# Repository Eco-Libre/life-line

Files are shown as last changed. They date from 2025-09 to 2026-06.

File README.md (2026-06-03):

# Eco-Libre Life-Line

This repo contains designs for an off-grid community's water system.

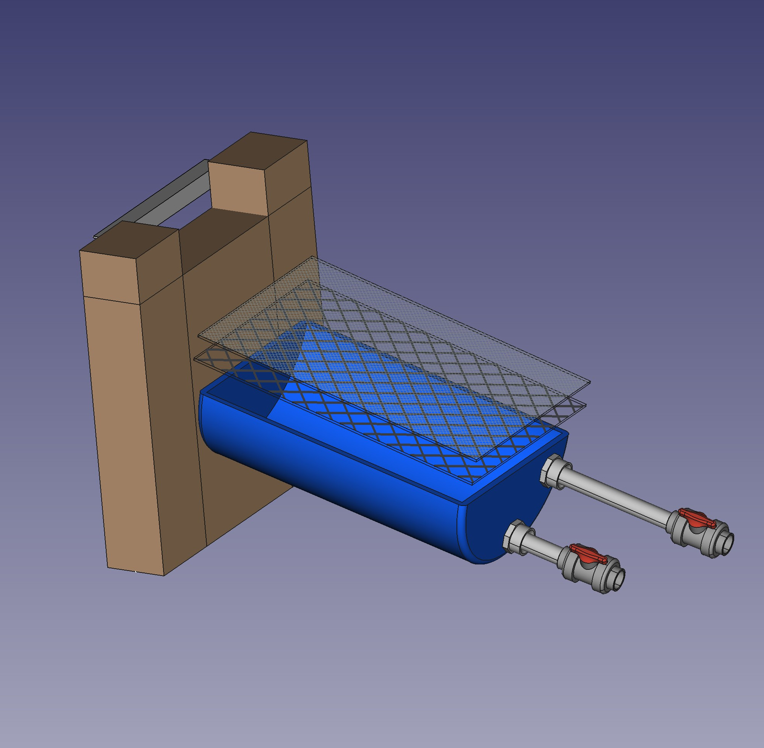
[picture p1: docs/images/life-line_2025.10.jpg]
Screenshot of CAD file
</a>

# Documentation

For more information (and build instructions), please see the [Eco-Libre Life-Line Documentation](https://eco-libre.github.io/life-line/)

 * https://eco-libre.github.io/life-line/

# License(s)

Copyright (C) 2023 Michael Altfield and Eco-Libre

The contents of this repo are licensed differently, depending on the 
file. In general:

 1. Most software files are licensed under AGPL-3.0-only

 3. Most other files are licensed CC-BY-SA-4.0

 4. Exceptions are defined according to the debian/copyright specification

To determine which license applies to which file, please see the 
`copyright` file. For more information on how to read and process 
this file, please see the specification here:

 * https://www.debian.org/doc/packaging-manuals/copyright-format/1.0/

The contents of this repo are distributed in the hope that it will be 
useful, but WITHOUT ANY WARRANTY; without even the implied warranty 
of MERCHANTABILITY or FITNESS FOR A PARTICULAR PURPOSE.  See the 
licenses under the LICENSES/ directory for more information.

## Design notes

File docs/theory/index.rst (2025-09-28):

.. _theory:

Theory
======

This section will describe the research behind this project and how it would benefit the lives of your community.

Concept
-------

The Eco-Libre Life-Line project is a system designed to collect, filter, and store surface water for an off-grid community.

Design Goals
------------

The water system should be:

#. Low-Maintenance
#. Hygienic

Low-Maintenance
---------------

**Low-Maintenance** means that low-tech automation and well-engineered, self-cleaning systems should be employed so that the system only needs routine maintenance once or twice per year.

Hygienic
--------

**Hygienic** means that the water stored in the clean water tanks and delivered to sinks should free of contamination (bacteria, parasites) and be safe to drink.

Size
----

**Pico (3-person)** (the smallest Eco-Libre Life-Line water system) should provide sufficient water for 3-people.

**Nano (15-person)** The small-size system should be horizontally scalable by multiplying the number of filters and tanks to provide sufficient water for a 15-person community

**Micro (30-person)** To handle a community of up to 30-people, a larger system design is provided.

**Milli (150-person)** To handle a community of up to 150-people, the micro system is horizontally scaled.

.. _theory_components:

Components
----------

Intake
^^^^^^

The water intake will consist of a weir on a stream with two openings with turbulence bars that channel turbulent water down onto a screen-covered 220-liter barrel angled at at downward slope.



  CAD Design of the Eco-Libre Life-Line's "Intake" component

This is a common low-budget, self-cleaning intake design that will shed organic debris during high-flow (eg a heavy rain).

The distance from the bottom of the weir to the top of the screen should be at least 20 cm.

The size of the holes in the screen should be 1-5 mm (it should be supported by a expanded metal screen below it).

The screen on the barrel should be mounted on a hinge to allow for routine maintenance.

Settling Tank
^^^^^^^^^^^^^

A radial-flow settling tank should be located very near to the intake and will remove sediment that passed the intake screen.

Large Sediment Filter
^^^^^^^^^^^^^^^^^^^^^

A self-cleaning spin down filter (largest size micron available) will remove debris that passed through the settling tank.

The flush valve should be automatically opened electronically by a timer.

Pre-Filter
^^^^^^^^^^

This pre-filter will remove turbidity from the water before it enters the slow sand filter.

This is `built <https://web.archive.org/web/20070728135100/http://www.refugeecamp.org/learnmore/water/slow_sand_filter.htm>`_ from a 220-litre HDPE drum that's filled with rocks and (mostly coarse) sand.

Slow Sand Filter
^^^^^^^^^^^^^^^^

The `Slow Sand Filter <https://en.wikipedia.org/wiki/Slow_sand_filter>`_ will remove harmful bacteria and parasites from the water.

This is `built <https://web.archive.org/web/20070728135100/http://www.refugeecamp.org/learnmore/water/slow_sand_filter.htm>`_ from a 220-litre HDPE drum that's filled with rocks and (mostly fine) sand.

Media Sediment Filter
^^^^^^^^^^^^^^^^^^^^^

A self-cleaning spin down filter (smallest size micron available) will remove filtering media debris (sand) that may have come-out of the filters

The flush valve should be automatically opened electronically by a timer.

Clean Water Tank
^^^^^^^^^^^^^^^^

The clean water tank stores potable water.

Lifeline
^^^^^^^^

Pipes supply clean water from the clean water tanks to the community.

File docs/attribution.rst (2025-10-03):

.. _attribution:

Attribution
===========

Thank you to the following folks who have contributed to the Life-Line project!
 * `Michael Altfield <maltfield_>`_
 * `Jack Nugent <jnugent_>`_
 * `Boris Plotkin <bplotkin_>`_
 * `Vegan Beasts <vbeasts_>`_

This project would not have been possible without the following tools and services:
 * `Python <https://www.python.org/>`_
 * `FreeCAD <https://www.freecad.org/>`_
 * `Vim <https://www.vim.org/>`_ 
 * `Gimp <https://www.gimp.org/>`_
 * `Kdenlive <https://kdenlive.org/en/>`_
 * `Sphinx <https://www.sphinx-doc.org/en/master/>`_
 * `Read The Docs <https://readthedocs.org/>`_
 * `Roboto Font <https://fonts.google.com/specimen/Roboto#about>`_
 * `Material Design Icons <https://github.com/google/material-design-icons>`_
 * `Wordpress <https://wordpress.com/>`_
 * `phpList <https://www.phplist.org/>`_
 * `QubesOS <https://www.qubes-os.org/>`_
 * `Debian <https://www.debian.org/>`_ `GNU <http://www.gnu.org/>`_/`Linux <https://www.kernel.org/>`_

Similar Projects
----------------

The reader may be interested to investigate the following similar projects:

 * `Gaviotas <https://en.wikipedia.org/wiki/Gaviotas>`_

.. _maltfield: https://www.michaelaltfield.net
.. _bplotkin: https://t.me/borisplot
.. _jnugent: https://github.com/Matterhorn777
.. _vbeasts: https://www.instagram.com/veganbeasts

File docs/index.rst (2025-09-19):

.. |nbsp| unicode:: 0xA0
   :trim:

Welcome to Eco-Libre's Life-Line documentation!
===================================================

Welcome! This is the official documentation for the Eco-Libre Life-Line.



  CAD Design of the Eco-Libre Life-Line

.. note::
   Just want to know **how to build the Eco-Libre Life-Line**?

   See our :ref:`Build Instructions <build>`

.. toctree::
   :maxdepth: 2
   :caption: What is the Life-Line?:
   :titlesonly:

   introduction/index
   theory/index
   praxis/index
   faq

.. toctree::
   :maxdepth: 3
   :caption: Build Instructions:
   
   build/index
   build/intake/index
   build/settling-tank/index
   build/large-sediment_filter/index
   build/pre_filter/index
   build/slow_sand_filter/index
   build/clean_water_tank/index
   build/lifeline/index

.. toctree::
   :maxdepth: 2
   :caption: Contributing:

   dev/index

.. toctree::
   :maxdepth: 2
   :caption: More:

   support
   changelog
   license
   attribution

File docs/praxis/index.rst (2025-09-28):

.. _praxis:

Praxis
======

This section will show example builds of the Eco-Libre Life-Line around the world.

Boris Plotkin
*************

In Nov 2024, `Boris Plotkin <bplotkin_>`_ built the first prototype of the Life-Line at the `Fruit Haven <fruithaven_>`_ community in Morona-Santiago, Ecuador

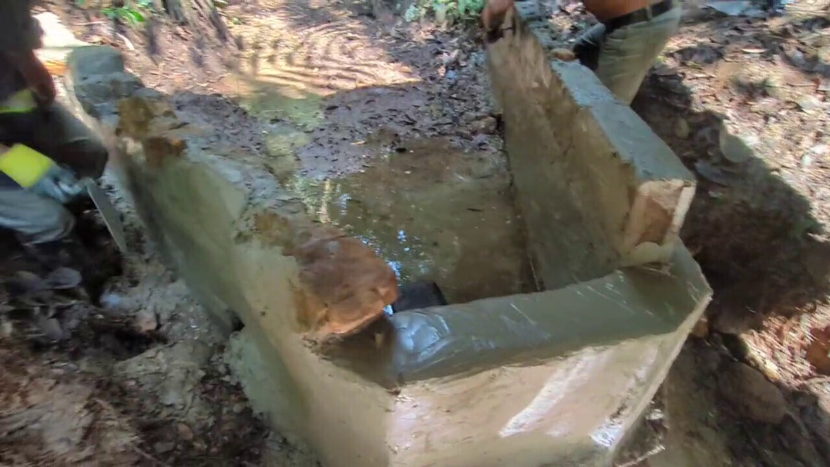
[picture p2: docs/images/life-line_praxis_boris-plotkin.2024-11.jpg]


  Concrete Block, Rock, and Cement Weir for the Eco-Libre Life-Line at Fruit Haven in Morona-Santiago, Ecuador (attribution: `Boris Plotkin <bplotkin_>`_)

Vegan Beasts
*************

In Apr 2025, `Vegan Beasts <vbeasts>`_ built the second prototype of the Life-Line at the `Fruit Haven <fruithaven_>`_ community in Morona-Santiago, Ecuador

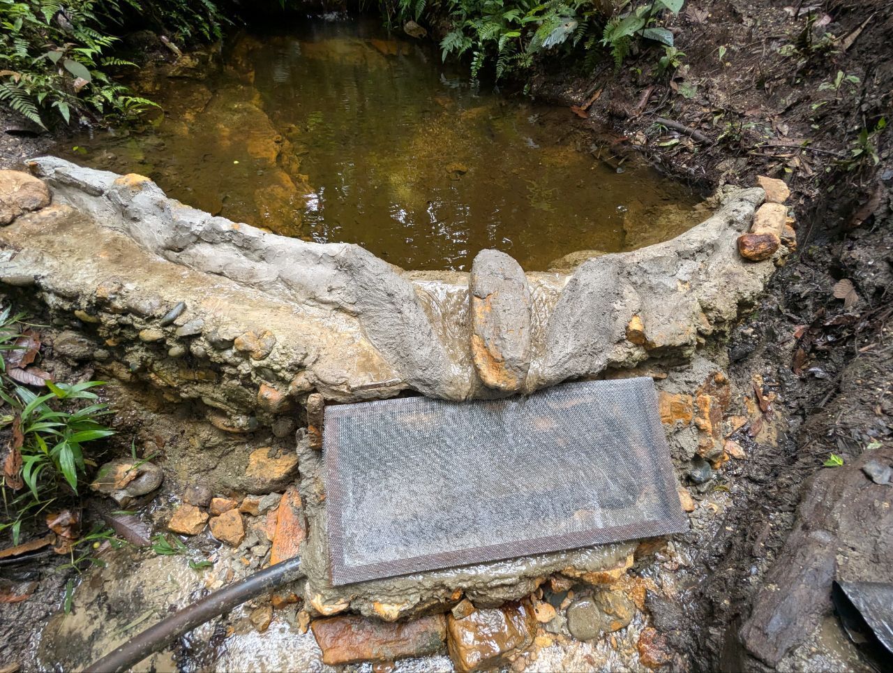
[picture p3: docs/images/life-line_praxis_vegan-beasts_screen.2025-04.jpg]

  
  Rock and Cement Weir for the Eco-Libre Life-Line at Fruit Haven in Morona-Santiago, Ecuador (attribution: `Vegan Beasts <vbeasts_>`_)

Get Listed!
***********

Did you build this? Please `let us know  <https://eco-libe.org/contact>`_ and we'll add your build to this page.

.. _bplotkin: https://t.me/borisplot
.. _fruithaven: https://fruithaven.land/
.. _vbeasts: https://www.instagram.com/veganbeasts

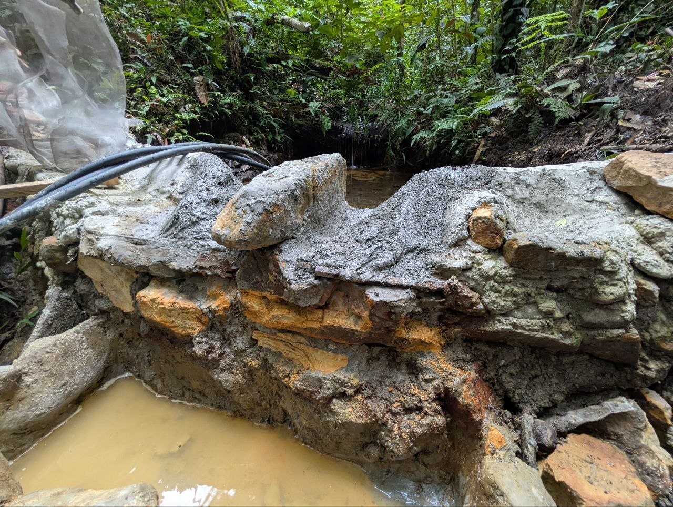
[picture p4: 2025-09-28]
docs/images/life-line_praxis_vegan-beasts_weir.2025-04.jpg

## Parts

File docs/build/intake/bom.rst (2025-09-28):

.. _intake_bom:

Bill of Materials
=================

This section will list the materials needed to build the Intake component of the Eco-Libre Life-Line project.

 ===== ======================================= ================== ======================================================================== ============= ======= =================== ============ ================================== ======================================================================================================================================================================================= ====================================================
  Qty   Item                                    Price (EUR)        Material                                                                 Weight (kg)   Color   Dimensions (mm)     Capacity     Tolerances                         Product URI (with price)                                                                                                                                                                Other Notes
 ===== ======================================= ================== ======================================================================== ============= ======= =================== ============ ================================== ======================================================================================================================================================================================= ====================================================
  2     Weir                                    759.69             Rocks, CEBs, Concrete Blocks, Bricks, and/or Steel-Reinforced Concrete                         1035 x 1000 x 500                                                   https://brooksonline.ie/kilsaran-kpro-crete-multi-purpose-concrete-25kg-un0427                                                                                                          Highly variable; price is minimum in just concrete
  1     Drum                                    109                HDPE                                                                     5.5           Blue    493 x 745           220 Liters                                      https://www.denios.ie/plastic-drums-with-bunghole-120-220-litre-volume-10300300451400/266140
  2     Steel Angle                             11.8256666666667   Steel                                                                                          650 x 60 x 6                                                        https://mybuildingsupplies.ie/shop/building-supplies/steel/steel-beams-steel-lengths-steel-sheets/steel-angle/
  4     M16 Concrete Anchor Bolt                8.664              Galvanized Steel                                                                               M16 x 100 mm                                                        https://www.screwfix.ie/p/rawlplug-throughbolts-r-xpt-m16-x-100mm-25-pack/657vc
  2     Fine Mesh Screen                        17.1792010250687   Stainless Steel                                                                                1000 x 665                       Holes 0.85 mm large (20 US Mesh)   https://www.ubuy.ie/en/product/MVOYTLARG-304-stainless-steel-mesh-47in-x-10ft-20-mesh-never-rust-sturdy-metal-mesh-screen-woven-wire-mesh-roll-for-window-screen-repl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
  2     Expanded Metal                          186.067            Galvanized Steel                                                                               1000 x 665                                                          https://www.lenehans.ie/steel-expanded-metal-sheet-1000mm-x-500mm.html
  4     Through-Wall Bushing (aka “bulkhead”)   120.68             PVC                                                                                            50 mm (2 inch)                                                      https://www.recifart.com/en/fitting/572-bulkhead-50mm.html
  2     50 mm Pipe                              15                 PVC                                                                                            1000 mm + 500 mm                                                    https://percolationsupplies.ie/product/50mm-pvc-piping/
  4     50 mm Valve                             55.32              PVC                                                                                            -                                                                   https://www.peservices.ie/product/ball-valve-pvc-u-50mm

 ===== ======================================= ================== ======================================================================== ============= ======= =================== ============ ================================== ======================================================================================================================================================================================= ====================================================

.. note::
   Want to **view the original spreadsheet** of the BOM above?

   You can download the ``docs/build/intake/bom.ods`` file from out `GitHub repo <github_repo_>`_ and open it on your computer in `LibreOffice <libreoffice_download_>`_

.. _github_repo: https://github.com/eco-libre/life-line
.. _libreoffice_download: https://www.libreoffice.org/download/

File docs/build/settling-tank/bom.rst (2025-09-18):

.. _setting_tank_bom:

Bill of Materials
=================

This section will list the materials needed to build the Settling Tank component of the Eco-Libre Life-Line project.

TODO

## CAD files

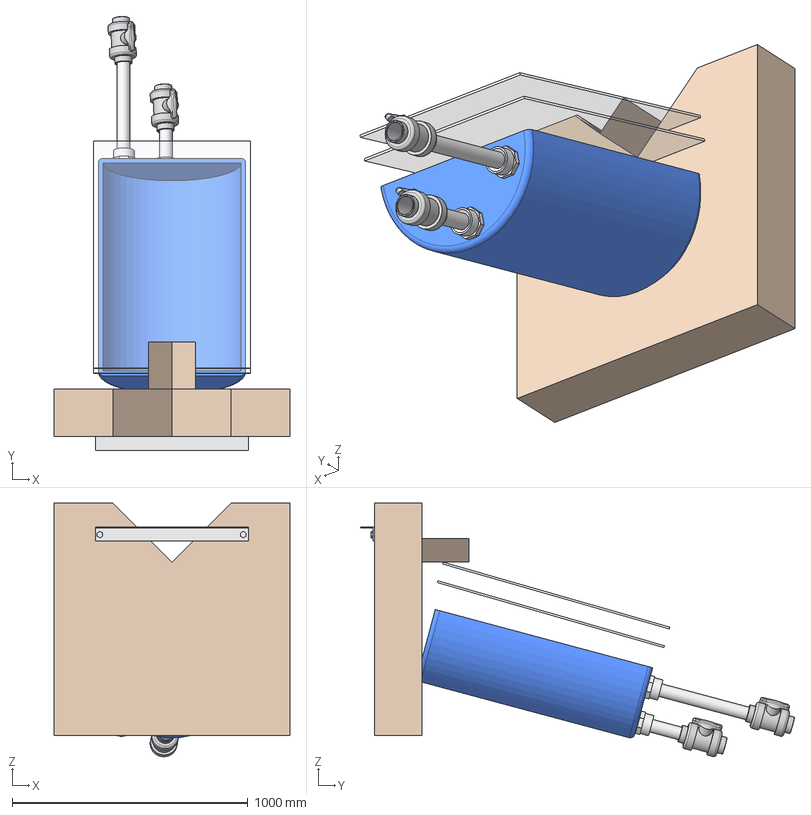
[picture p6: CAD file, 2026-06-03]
cad/intake.FCStd
1000.0 x 1840.7 x 1075.2 mm
intake drum
expanded-metal-002_cube
expanded-metal-002_facebinder
hex-bolt-M16-40mm-002
hex-bolt-M16-40mm-001
turbulance-bar-001
2in-bushing-002
2in-pipe-001
2in-pvc-valve-002
2in-pvc-valve-001
2in-bushing-001
2in-pipe-002
fine-mesh-screen-002_cube001
fine-mesh-screen-002_facebinder001
weir-opening-traingle_cut
weir-opening-lip_extrude

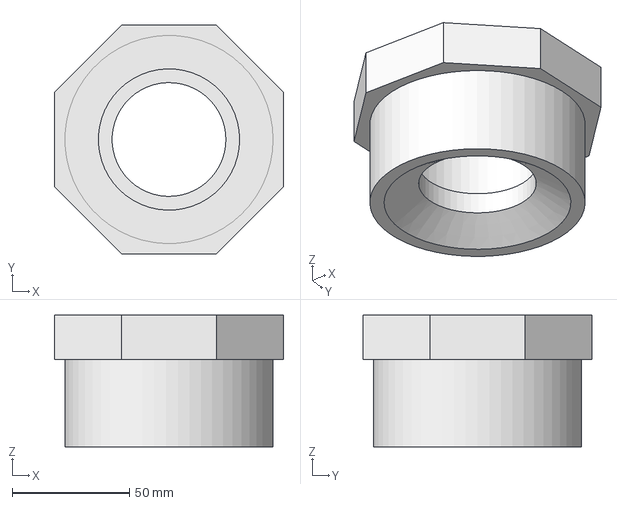
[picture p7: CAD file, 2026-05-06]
cad/bushing_837-338.FCStd
97.8 x 97.8 x 56.4 mm

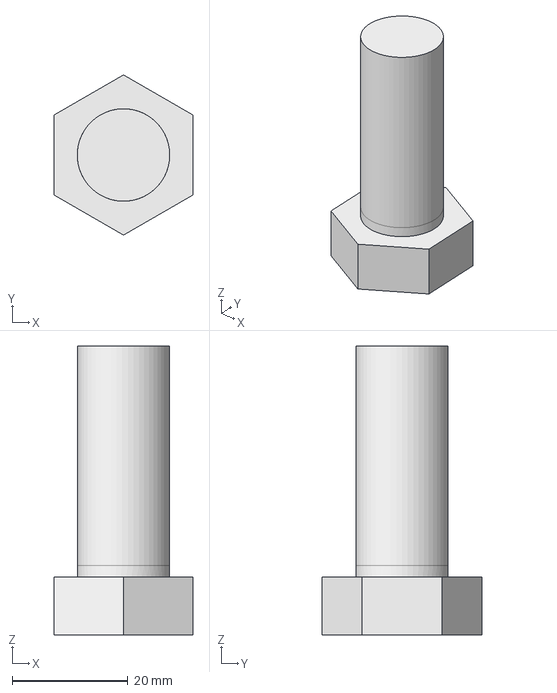
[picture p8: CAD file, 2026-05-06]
cad/m16_40mm.FCStd
24.0 x 27.7 x 50.0 mm

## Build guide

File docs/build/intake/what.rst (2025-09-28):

.. _intake_what:

What is the "Intake" Component?
===============================

This section will describe how to build the "Intake" component of the Eco-Libre Life-Line system.



  CAD Design of the Eco-Libre Life-Line's "Intake" component

.. contents::
   :local:

.. note::
   Want to **view the 3D Model** of the Intake Compoenent above?

   You can download the ``intake.FCStd`` file from out `GitHub repo <github_repo_>`_ and open it on your computer in `FreeCAD <freecad_download_>`_

The "Intake" component is responsible for raw water capture from a stream. The design of >=20cm falling, turbulent water is self-cleaning: the turbulent water falls onto the screen with sufficient force to clear debris off of the screen. This ensures constant raw water collection into the Life-Line system, without requiring periodic manual human intervention (or automatic moving parts) needed to remove debris blocking the ingest of water into the system.

The "Intake" component is made-up of several parts:

.. _intake_weir:

1. Weir
-------

The Weir is a masonry structure (CEB, Concrete Block, or Steel-reinforced Concrete) that's built in the middle of a stream. It has a Weir Opening at the top, which channels falling water to flow ontop of a :ref:`metal screen <intake_screen>` and into a :ref:`water collection drum <intake_drum>`.

.. list-table::

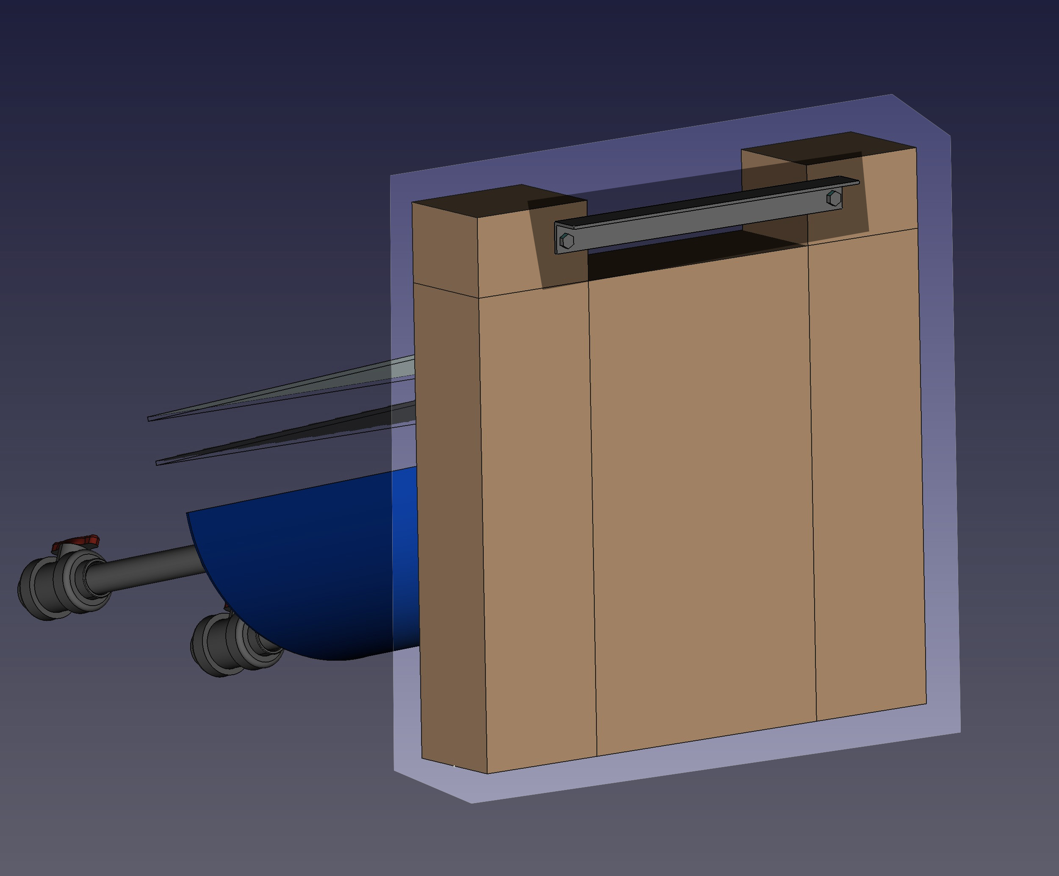
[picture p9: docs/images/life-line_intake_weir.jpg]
Screenshot of FreeCAD, highlighting a long blue drum that's cut in half
        * - 

	  - Photo of a freshly-constructed rock-and-concrete-block weir

The distance between the bottom of the Weir Opening and the top of the :ref:`Fine Mesh Screen <intake_screen>` atop the :ref:`water collection drum <intake_drum>` must be at least 20 cm. If the water falls less than 20 cm, it will not have enough force to self-clean the :ref:`screen <intake_screen>` of organic debris.

.. _intake_turbulence_bar:

2. Turbulence Bar
-----------------

The Turbulence Bar is a piece of steel angle that's bolted to the :ref:`weir <intake_weir>`, bisecting the Weir Opening.

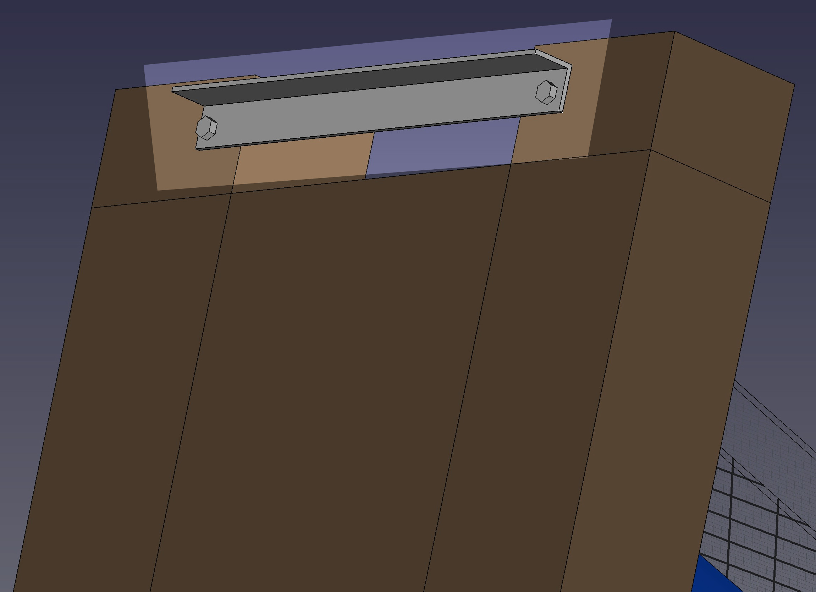
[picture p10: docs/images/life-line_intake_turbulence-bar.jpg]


  The Life-Line "Intake" component's Turbulence Bar

The Turbulence Bar changes the flow of the water as it passes through the Weir Opening, creating turbulence. This turbulant water is more effective at self-cleaning the :ref:`screen <intake_screen>` below of organic debris than non-turbulant falling water.

.. _intake_screen:

3. Fine Mesh Screen
-------------------

The Fine Mesh Screen is a very fine metal screen that's designed to filter-out large organic materials (eg leaves, sticks, stones, grass, etc) from entering the :ref:`drum <intake_drum>`.

.. list-table::

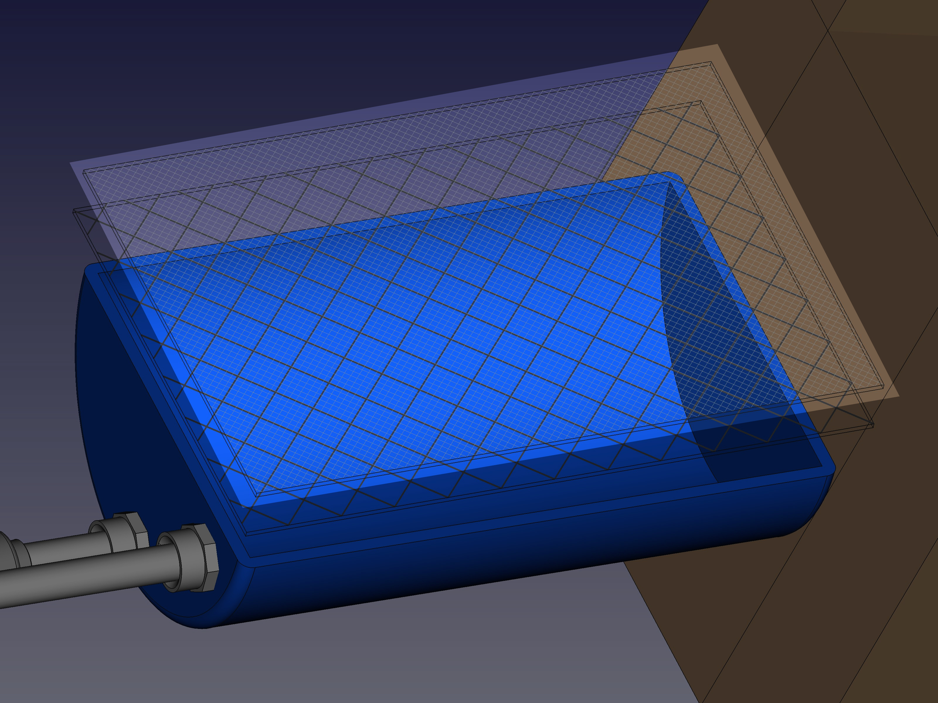
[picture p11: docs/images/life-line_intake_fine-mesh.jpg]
Screenshot of FreeCAD, highlighting a mesh screen ontop of a long blue drum cut in half
        * - 

	  - Photo of a rock-and-concrete-block weir pouring over a fine mesh screen

The Fine Mesh Screen should be made of Stainless Steel, and the holes in the screen should be approximately 0.85 mm large (20 `US Mesh <20mesh_>`_)

.. _intake_expanded_metal:

4. Expanded Metal Mesh
----------------------

The Expanded Metal Mesh is a strong grate made of Expanded Metal that sits below the :ref:`Fine Mesh Screen <intake_screen>` and atop the Drum

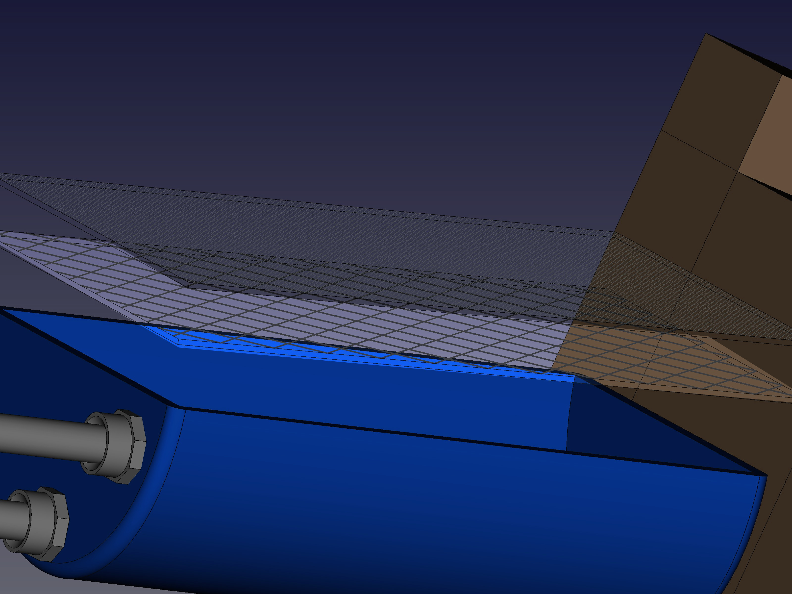
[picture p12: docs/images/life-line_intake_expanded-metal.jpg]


  The Life-Line "Intake" component's Expanded Metal Mesh

The purpose of the Expanded Metal Mesh is to provide a physical support structure for the :ref:`Fine Mesh Screen <intake_screen>` above it.

.. _intake_outflow_pipe:

5. Outflow Pipe
---------------

The Outflow Pipe is where water flows out of the Intake :ref:`drum <intake_drum>` and into the next component of the Eco-Libre Life-Line system (the :ref:`settling_tank` Component)

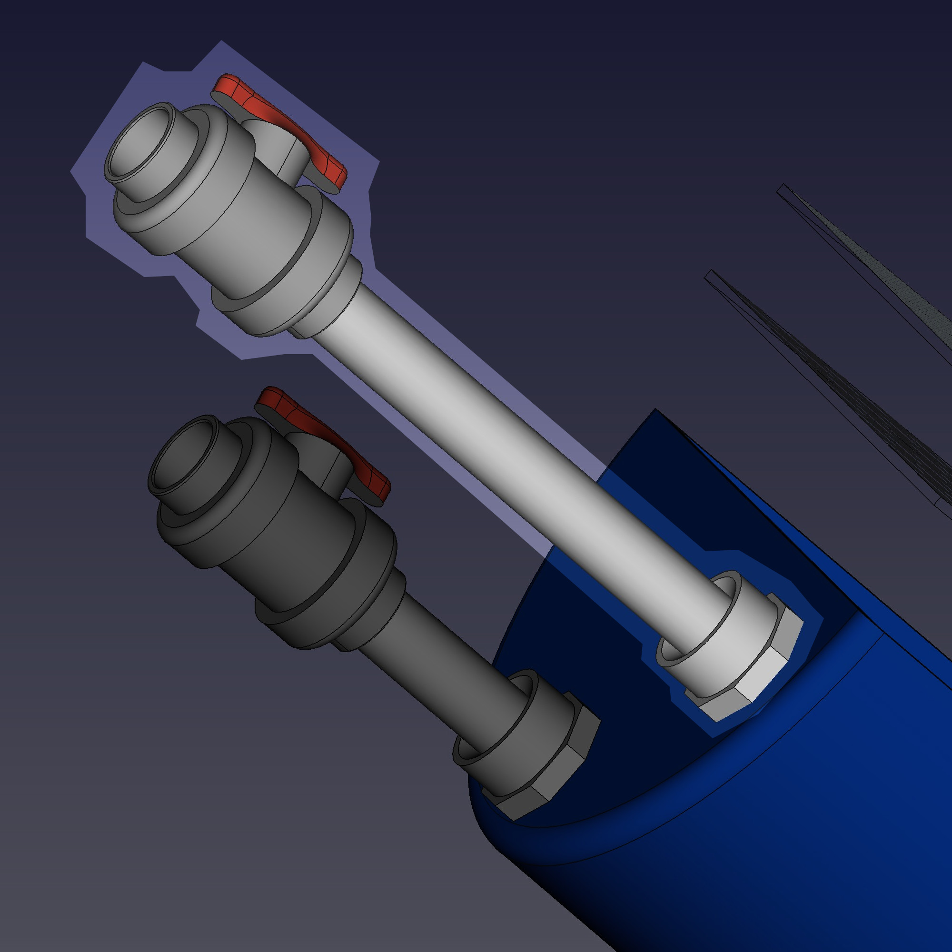
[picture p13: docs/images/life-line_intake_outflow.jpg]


  The Life-Line "Intake" component's Outflow Pipe

The outflow pipe consists of a Bushing, Pipe, and Valve.

.. _intake_drain_pipe:

6. Cleanout Drain Pipe
----------------------

The Cleanout Drain Pipe is located at the bottom of the :ref:`drum <intake_drum>`, next to the :ref:`Outflow Pipe <intake_outflow_pipe>`.

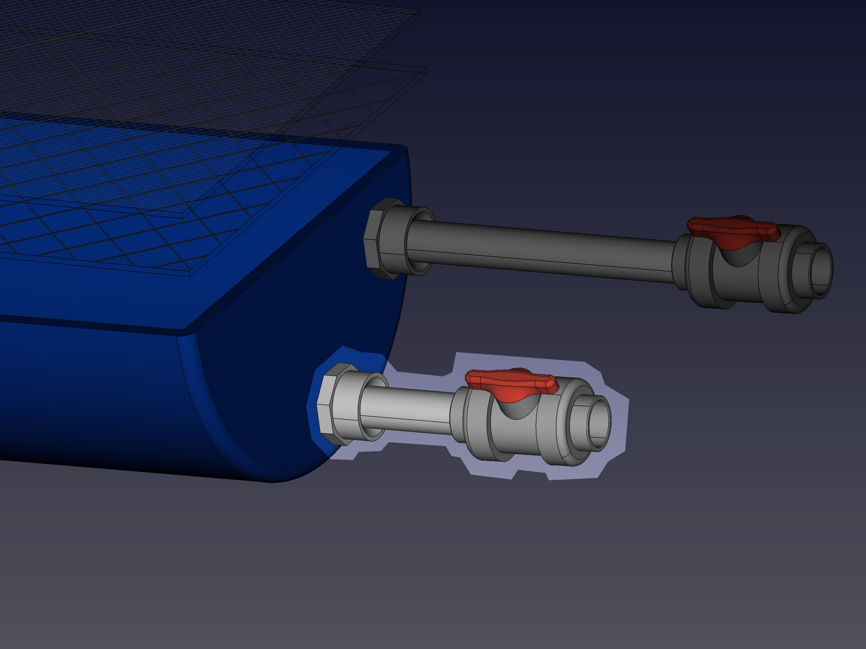
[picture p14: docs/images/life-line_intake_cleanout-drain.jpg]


  The Life-Line "Intake" component's Cleanout Drain Pipe

The Cleanout Drain Pipe consists of a Bushing, Pipe, and Valve.

The purpose of the Cleanout Drain Pipe is to flush small debris (eg sand) that have collected at the bottom of the drum. In normal operations, the valve should be closed. During routine maintenance (at least once per year), the Cleanout Drain Pipe should be opened, to flush-out any debris that have settled at the bottom of the drum.

If possible, a valve actuator (eg a simple electronic sprinkler system on a timer) could be placed after the valve to automatically flush the drum on a routine basis.

.. _intake_drum:

7. Drum
-------

The Drum is a standard 220L (55 gallon) HDPE barrel drum that's been cut in half length-wise.

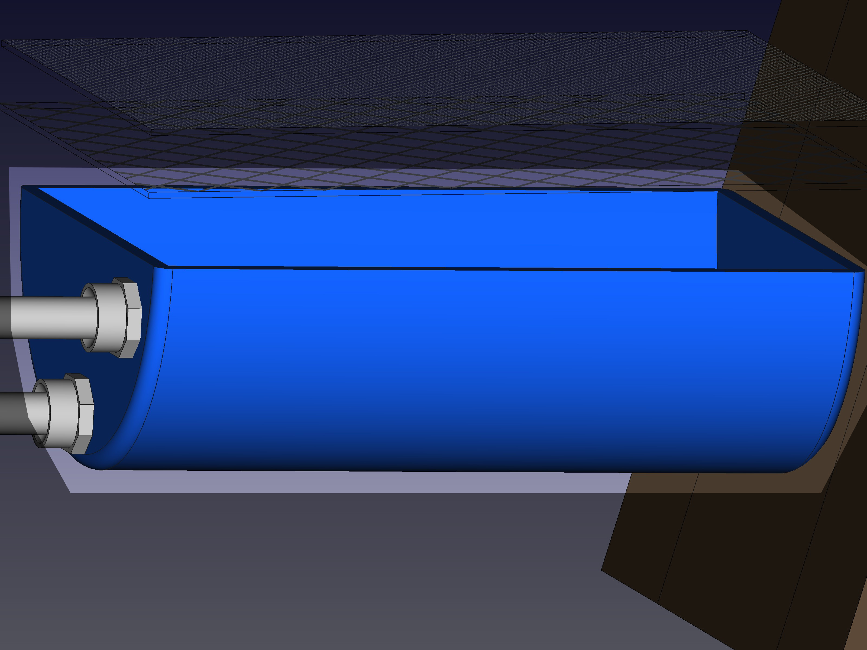
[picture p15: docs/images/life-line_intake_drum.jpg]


  The Life-Line "Intake" component's Drum

The drum collects water as it spills over the weir and onto the :ref:`metal mesh screen <intake_screen>` that sit atop the cut-open face of the drum.

Two holes are cut on the downstream side of the drum, where through-wall bushings are placed for the :ref:`Cleanout Drain Pipe <intake_drain_pipe>` and the :ref:`Outflow Pipe <intake_outflow_pipe>`.

.. _20mesh: https://en.wikipedia.org/wiki/Mesh_(scale)
.. _github_repo: https://github.com/eco-libre/life-line
.. _freecad_download: https://www.freecad.org/downloads
.. _bplotkin: https://t.me/borisplot

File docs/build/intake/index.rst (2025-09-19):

.. _intake:

Intake
======

This section will describe how to build the "Intake" component of the Eco-Libre Life-Line system.

.. toctree::
   :maxdepth: 3
   :caption: Table of Contents

   what
   bom

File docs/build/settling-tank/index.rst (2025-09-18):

.. _settling_tank:

Settling Tank
=============

This is a section that will talk about how to build the "Settling Tank" component of the Eco-Libre Life-Line system.

.. toctree::
   :maxdepth: 3
   :caption: Table of Contents

   what
   bom

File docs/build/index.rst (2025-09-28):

.. _build:

Getting Started
==================

This section will document how to build the Eco-Libre Life-Line.

.. note::
	You can view the documentation to build a previous version by selecting a different version in the bottom-left menu

The Eco-Libre Life-Line project is made up of several distinct components. We have separated the build instructions into different sections to build each component.

Click on the component below to view its build instructions.

.. toctree::
   :maxdepth: 1
   :glob:

   */index

For an overview of what each component is, see :ref:`Theory <theory_components>`

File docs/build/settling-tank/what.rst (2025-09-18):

.. _settling_tank_what:

What is the "Settling Tank" Component?
======================================

This is a section that will talk about how to build the "Settling Tank" component of the Eco-Libre Life-Line system.



  CAD Design of the Eco-Libre Life-Line's "Settling Tank" component

.. note::
   Want to **view the 3D Model** of the Settling Tank Compoenent above?

   You can download the ``settling-tank.FCStd`` file from out `GitHub repo <github_repo_>`_ and open it on your computer in `FreeCAD <freecad_download_>`_

The "Settling Tank" compoenent is responsible for raw water capture from a stream. It's made-up of several parts:

1. TODO
-------

TODO

2. TODO
-----------------

TODO

.. _github_repo: https://github.com/eco-libre/life-line
.. _freecad_download: https://www.freecad.org/downloads

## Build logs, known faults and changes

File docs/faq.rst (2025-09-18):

.. _faq:

Frequently Asked Questions
==========================

.. _faq_follow:

Q: How can I get updates about Eco-Libre?
-----------------------------------------

You can `signup for our Eco-Libre email newsletter <https://www.eco-libre.org/newsletter>`_ or follow us on any of the following social media profiles:

* Twitter `@EcoLibreNews <https://twitter.com/EcoLibreNews>`_
* Facebook `@EcoLibreNews <https://www.facebook.com/EcoLibreNews/>`_
* Mastodon `@ecolibre@chos.social <https://chaos.social/@ecolibre>`_
* GitHub `Eco-Libre <https://github.com/eco-libre>`_
* YouTube `@Eco-Libre <https://www.youtube.com/@Eco-Libre>`_

.. _faq_cost:

Q: How much does it cost to build this system?
----------------------------------------------

See :ref:`intake_bom`

.. _faq_bom:

Q: What do I need to buy to build this?
---------------------------------------

See :ref:`intake_bom`

.. _faq_build:

Q: Where can I find the instructions to actually build it?
----------------------------------------------------------

See our :ref:`Build Instructions <build>`

.. _faq_examples:

Q: Has anyone else built this before?
-------------------------------------

Yes. See :ref:`praxis`

.. _faq_cad:

Q: Where can I download the 3D Models?
--------------------------------------

You can download our source `FreeCAD <freecad_download_>`_ files from out `GitHub repo <github_repo_>`_.

.. _faq_commercial:

Q: Can I sell this?
-----------------------------

Please do!

All of Eco-Libre's work is libre or open source, pursuant to the `Open Source Hardware Association definition <oshwa_definition_>`_.

You're welcome to take our designs and use them for commercial purposes, so long as

#. You provide prominent attribution back to Eco-Libre (link to `our website <https://eco-libre.org>`_) and
#. You must make public any modifications that you make to our work, and you must also license your derivative works under a compatible ShareAlike license.

For more information, see :ref:`license`

.. _faq_support:

Q: My questions isn't listed. Where can I get support?
------------------------------------------------------

Please see :ref:`support`

.. _github_repo: https://github.com/eco-libre/life-line
.. _freecad_download: https://www.freecad.org/downloads
.. _oshwa_definition: https://www.oshwa.org/definition/

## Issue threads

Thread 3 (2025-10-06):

Fix pdf builds

maltfield, 2025-10-06:
This issue will track the effort to fix the sphinx pdf builds with rinoh

maltfield, 2025-10-06:
I also created two bug reports with rinoh because their documentation (both on pypi and their github pages) produces these errors when you follow it:

 * https://github.com/brechtm/rinohtype/issues/448
 * https://github.com/brechtm/rinohtype/issues/449

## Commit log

2025-09-16 manual merge from https://github.com/Matterhorn777/life-line
    This commit finishes a manual merge from Jack Nugent's contributions.
    Unfortunatley, Jack left Eco-Libre before finishing his PR. His changes
    include documentation and updates to intake.FCStd. As it was,
    intake.FCStd was a (compressed) file size of 17 MB, and an
    (uncompressed) MemSize of 114.8 MB.
    I didn't want to merge this huge file into git, as it would have caused
    bloat for all future clones. Instead, I decided to make the changes
    locally and then just rsync it in.
    Currently the file is 3.6 MB (compressed) and has an (uncompressed)
    MemSize of 11.1 MB. Further improvements could be done to the ~2 MB bung
    pipe couplers, but th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
    [intake.FCStd]
2025-09-16 added hatch to expanded-metal-002
    This commit did the facebinder -> hatch process to the sold that
    replaced the expandedMetal001 object in our last commit.
    For more info, see:
    * https://eco-libre.org/expanded-metal-hatch-freecad/
    [intake.FCStd]
2025-09-16 deleted tin roof
    This commit deleted the "tin roof" over the intake weir/drum
    If the system functions properly, then any debris (eg leaves falling
    from trees) should be cleaned-away from the intake screen by the
    turbulant water falling on the screen. So the roof adds nothing good,
    while blocking the view of the system in the CAD diagram does something
    bad for it serving as a visual aid in the documentation
    [intake.FCStd]
2025-09-16 update image and docs
    This commit adds a new screenshot of the intake for our upcoming 2025.10
    release. I updated it in the docs, and also made some other basic syntax
    fixes in the docs
    TODO: fix the BOM tables for the intake in the docs
    [intake.FCStd]
2025-09-16 fixed the bom tables
    this commit fixes Jack's "bill of materials" page of the documentation
    for the intake. THis is mostly just cosmetic syntax changes. There's
    still errors in the contnet that should be fixed.
2025-09-16 added first prototype to docs
    This commit adds an image (and attribution) for the first prototype of
    the Life-Line, created by Boris in Ecuador.
2025-09-16 simplified bulkhead = bushing in intake.FCStd
    This commit made further progress on the optimization/simplification of
    the intake.FCStd file by focusing on its largest objects:
    1,908,593 | Bulkhead Body001
    1,908,590 | Bulkhead Body
    Each of these items was about 1.8 MB large. They were unnecessary
    complicated parts, complete with threads.
    To replace them, I used the Open Source Ecology Piping Workbench:
    * https://wiki.opensourceecology.org/wiki/OSE_Piping_Workbench#Installation
    This let me generate a Bushing in one-click (a bushing is another name
    for a through-wall bulkhead). The size I selected was identified as part
    "837-338" -- which has the following attributes:
    * Part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
    [intake.FCStd]
2025-09-17 simplified 2" valves
    This commit optimizes the intake.fcstd file by replacing the
    overly-complex actuators with simple 2" pvc vaves.
    The old MemSize was
    -------------------------------
    MemSize (bytes) | Object Label
    -------------------------------
    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
    [intake.FCStd]
2025-09-17 simplified turblence bars
    This commit deleted the overly-complex model of the turbulance bar (and
    its two bolts) to reduce the size of the inktake.fcstd file and optimize
    future edits.
    I measured the previously-existing steel angle to be 650mm long, about
    37mm wide (from the 90 degree angle), and about 5.75 mm thick.
    I did a quick check for common angle sizes in metric, and I found 60 mm
    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
    [intake.FCStd]
2025-09-17 simplified pipes
    This commit replaced the unnecessarily complex pipes (with threads) with
    very simple tubes.
    I first considered using the BOLT library to produce a pipe, but instead
    I used the built-in "tube" primitive, available in the stock Part
    workbench.
    Here's the original MemSize:
    1,166,273 | intake
    180,035 | intake_Outflow_Pipe_001
    180,035 | intake_Outflow_Pipe_002
    155,122 | 2in-pvc-valve-001
    155,122 | 2in-pvc-valve-002
    And after this change:
    823,3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
    [intake.FCStd]
2025-09-18 organized objects into groups
    This commit didn't actually change any of the objects modeled in
    intake.FCStd; it only created some groups, moved the objects in the tree
    around into those groups, and deleted some objects that seemed to be
    unnecessary.
    This is just a reorganizing and "cleanup" commit
    [intake.FCStd]
2025-09-18 updated images
    This commit updates the main image of the intake
    (life-line_2025.10.jpg), since I've made the numerous optimizations to
    the file in the last week.
    I also made an SVG file that takes the above raster image and adds some
    numbers and arrows to identify different parts. I can use this in the
    documentation to describe, in a few sentences, what each of these items
    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
    [intake.FCStd]
2025-09-18 lots of docs changes
    This commit makes a lot of changes to the sphinx documentation, most
    importantly to the faq section and the intake "build instructions"
    section.
    We now have an svg image with 7 numbers pointing to 7 different
    sub-components of the "intake". And at least 2 paragraphs and a photo
    for each of these
    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
2025-09-19 fixed docs bom for intake
    This commit adds a new file 'bom.ods'. It makes more sense long-term to
    use a proper spreadsheet for a BOM, and this one uses the open-source
    LibreOffice format. The format isn't great for git, but with tools like
    ReZipDoc, we can get git to unzip FreeCAD and LibreOffice files, to
    save repo space and get better diffs
    * https://github.com/hoijui/ReZipDoc
    For now, I just exported the contents of the .ods file to a .csv file,
    and used a quick online converter tool to have it convert the csv to
    reST format
    * https://tableconvert.com/csv-to-restructuredtext
    In the future, we should write a sphinx directive that can import the
    .ods file directly into the documentati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
    [bom.ods]
2025-09-28 update docs
    updated CHANGELOG
    added TOC and intro paragraph for the index of the build section, to make it more clear
    added note linking to the BOM source spreadsheet
    added a "contents" directive to the "intake/what.rst". This is better
    than the "TOC" as it (with the "local" option) *only* shows the headings
    on the local page, which is perfect for our svg diagram above it, so
    people can quickly click on the numbers to read about the sub-component
    that it points-to
    fixed side-by-side images (cad & example) by adding "list-table"
    directive to the intake/what.rst
    added "vegan beasts" prototype to "praxis" page
    added example of vegan beasts' prototype for the "fine mesh screen"
    sub-compone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
2025-10-03 attempt to fix links to other versions in docs
    This commit updates conf.py with some code that attempts to fix the
    "versions" links in the left-hand navbar (which currently don't appear
    at all on the GitHub build, though they're fine locally)
    I also added a cool community that I learned about today, which did very
    similar work as Eco-Libre (development of Appropirate Technology in
    South America) in Colombia in the 1970s
    * https://en.wikipedia.org/wiki/Gaviotas
    * https://www.chelseagreen.com/product/gaviotas/
    * http://www.friendsofgaviotas.org/
2025-10-06 attempt to fix epub & pdf builds
    This commit fixes a typo to the epub build.
    This commit also updates the buildDocs.sh script to create a virtual
    environment in python before attempting to install the rinoh dependency
    necessary to build the pdf file from our docs. Currently we have an
    error, which is resolved by first creating (and activating) a python
    venv. Note that we prefer to install in apt, but this rinoh python module isn't available in apt..
    * https://github.com/Eco-Libre/life-line/actions/runs/18245009027/job/51951774559
    2025-10-04T13:33:09.2827810Z + python3 -m pip install --upgrade rinohtype pygments
    2025-10-04T13:33:09.5003378Z WARNING: The directory '/github/home/.cache/pip'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
2025-10-06 attempt to fix pdf builds
    This commit attempts to fix the build of the pdf file by copying the
    Debian apt-installed python packages into the venv, which was needed to
    fix the rinoh pip install (in last commit), but (as it turns out) does
    not include the already-installed modules, such as git -- which is
    breaking the builds
    * https://github.com/Eco-Libre/life-line/actions/runs/18266555954/job/52001748875
    2025-10-06T00:29:42.0566266Z INFO: Building for en
    2025-10-06T00:29:42.0566518Z + for current_language in ${languages}
    2025-10-06T00:29:42.0566771Z + export current_language
    2025-10-06T00:29:42.0566984Z + echo 'INFO: Building for en'
    2025-10-06T00:29:42.0567288Z + sphinx-build -b html docs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
2025-10-10 add debug output to pdf build
    This commit adds '-vvv' to the `sphinx-build` command where we're
    building the pdf document. Since it appears to be getitng stuck (maybe
    on an infinite loop), I'm hoping that additional output can tell us
    *where* it's stuck, so we can either fix it or open a bug report
    upstream
    * https://github.com/Eco-Libre/life-line/actions/runs/18391943167/job/52403773308
    2025-10-09T23:35:48.9187429Z + sphinx-build -b rinoh docs/ docs/_build/rinoh -D language=en
    2025-10-09T23:35:49.0654144Z ␛[01mRunning Sphinx v8.2.3␛[39;49;00m
    2025-10-09T23:35:49.1001303Z ␛[91mWARNING: Invalid configuration value found: 'language = None'. Update your configuration to a valid languag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
2025-11-13 lowered the weir to match the height of the intake barrel (plus 20 cm).
    Our docs indicate that the barrel needs to be located at least 20 cm
    below the weir opening, but we had some math in-place for the height of
    the weir (notch bottom) to be 585 cm high plus 20 cm. But the height of
    the top-edge of the downsloped intake barrel wasn't at a base of 585 cm
    off the ground. It's only about 536 mm off the ground. So I fixed that.
    [intake.FCStd]
2025-11-13 created spreadsheet
    For a more robust design, I'm building on the last commit by putting
    some of these dimensions into a spreadsheet. And the following objects
    now reference the spreadsheet, to determine their size and/or placement:
    1. Weir (notch bottom)
    2. Weir (notch top)
    3. Turbulance Bar
    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
    [intake.FCStd]
2025-11-13 updated weir sketches to use Spreadsheet
    this commit adds construction geometry to the sketches used to build the
    weir walls, based on the dimensions set in the spreadsheet
    [intake.FCStd]
2025-11-13 created sketch of 'weir-opening-triangle'
    This commit created a fully constrained sketch of a
    "weir-opening-triangle", which we'll use to "cut out" from the weir
    opening, to make it a V-shape (better for low water flow conditions)
    [intake.FCStd]
2025-11-13 extruded triangle cutout
    This commit finished extruding and raising-up the triangle cutout of our
    weir, but I made a mistake: the triangle is upside down! We want the
    point of the triangle to be facing down!
    TODO: re-draw the triangle, so that the point is downward, directing the
    smallest flow of water along a single line, then increasing its spread
    as the flow increases
    [intake.FCStd]
2025-11-13 triangle flipped
    This commit flips the upside-down triangle created in the last commit
    TODO: cut it out of the weir wall!
    [intake.FCStd]
2025-11-13 cut the triangle out of the weir
    This commit finishes the "cut" that subtracts the upside-down triangle
    out of the weir wall, to creat a triangular weir opening. This change
    increases the efficiency of the water collection in low-rain/low-flow conditions, such that a slow trickle is directed at a single point over the drum.
    TODO: add a "lip" to ensure that 100% of the water coming out of the
    weir opening in low-flow conditions gets dropped directly over the drum
    [intake.FCStd]
2025-11-13 added 'weir-opening-lip' sketch
    This commit adds a new sketch (weir-opening-lip), which pulls-in the
    external geometry of the weir-opening-triangle that we created earlier
    today.
    TODO: extrude and move this up to the same location of the triangle, so
    there's a "lip" on the weir opening that directs low-flow water
    *directly* over the intake drum
    [intake.FCStd]
2025-11-13 finished weir opening lip
    This commit finishes adding the extruded "lip" of the weir opening,
    which directs 100% of the water in low-flow conditions to drop directly
    over the drum
    For more info on why this is important, see the article about v2025.10
    and the problems we found with two prototypes here:
    * https://www.eco-libre.org/life-line-2025-10-released/
    [intake.FCStd]
2026-04-28 added licenses and REUSE.toml
    This commit improves our licensing, which licenses different types of
    files under different types of licenses, whichever is best for the file
    type.
    For this we're using the REUSE tool and standard. For more info, see:
    * https://forums.ohwr.org/t/licensing-an-ohl-w-derivative-as-ohl-s/849101
    * https://wiki.eco-libre.org/wiki/Maltfield_Log/2026
    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
    [intake.FCStd]
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2026-05-06 added bushing & copyright
    This commit adds a separate cad file just for the 837-338 bushing that
    we created using the OSE Piping Workbench back in Sep 2025
    * https://github.com/rkrenzler/ose-piping-workbench
    * https://wiki.opensourceecology.org/wiki/OSE_Piping_Workbench
    * https://github.com/Eco-Libre/life-line/commit/2352894d58c739b3792c69a9662a62f3123e670e
    I recreated it in a standalone cad for the purposes of adding it as an
    "Available Component" for which we can copyright and license separately.
    While I don't think we legally have to do this (that's one of the issues
    of using GPL for hardware), it's part of my effort to provide an example
    repo for CERN
    * https://forums.ohwr.org/t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
    [bushing_837-338.FCStd]
2026-05-06 added GPL-3.0-or-later license file
    This commit adds the GPL 3.0 to the LICENSES/ dir.
    While we don't use this license for any of *our* content, it was used by
    an "Available Component" created by an upstream pipe tool (from OSE).
    See last commit for more details. This just fixes the `reuse lint` error
    for the missing license
    (reuse) user@disp6671:~/life-line$ reuse lint
    # MISSING LICENSES
    'GPL-3.0-or-later' found in:
    * cad/bushing_837-338.FCStd
    # SUMMARY
    * Bad licenses: 0
    * Deprecated licenses: 0
    * Licenses without file extension: 0
    * Missing licenses: GPL-3.0-or-later
    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
2026-05-06 added 40mm m16 bolt
    This commit adds a separate file for a 40 mm m16 bolt that was generated
    using the BOTLS package, which is licensed separately (under L
    [m16_40mm.FCStd]
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2026-05-06 update intake license metadata to "other" with URL
    * https://ohwr.org/cern_ohl_s_v2.txt
    [intake.FCStd]
2026-06-03 reverting to dual-license of GPLv3 & CC BY-SA 4.0
    This commit reverts back to our original license, which we had been
    using before 2026-04-28.
    Less than 2 months ago, after reading the OSHWA best practices guide, I
    decided to relicense our hardware files under CERN-OHL-S-2.0. This was a
    mistake.
    * https://oshwa.org/resources/sharing-best-practices/
    Since then, I learned from Javier Serrano (Deputy Group Leader of the accelerator Controls Electronics and Mechatronics and co-author of the CERN OHL license) that licensing our CAD files under CERN-OHL-S-2.0 would prevent us from including components that are licensed CC BY-SA. That would be an issue if, for example, we wanted to extrude a pa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
2026-06-03 relicensing to AGPL + CC BY-SA + exceptions
    This commit find the best middle-ground from our old GPL & CC BY-SA
    licensing (which we just reverted-to in our last commit) and our failed
    attempt to relicense using the CERN license for hardware files, AGPL for
    software, CC BY-SA for all else, and exceptions defined in the REUSE
    format.
    Here we're switching GPL to AGPL, because it's not an issue and in-fact
    better for copyleft intentions (regardless of if we make network-based
    software -- that remains to be seen) and keeping CC BY-SA for all else.
    But, we also have some exceptions -- like when we include a bolt from a
    project that's LGPL.
    I decided to use the Debian copyright format (formerly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
    [intake.FCStd]
